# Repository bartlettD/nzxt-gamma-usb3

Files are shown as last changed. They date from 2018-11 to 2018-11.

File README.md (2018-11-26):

# NZXT GAMMA I/O Panel

Replacement front I/O panel for NZXT GAMMA PC case with USB 3.0 ports.

Designed in Autodesk EAGLE v 9.2

PDF Schematics and Board Images are available in the "Docs" directory.

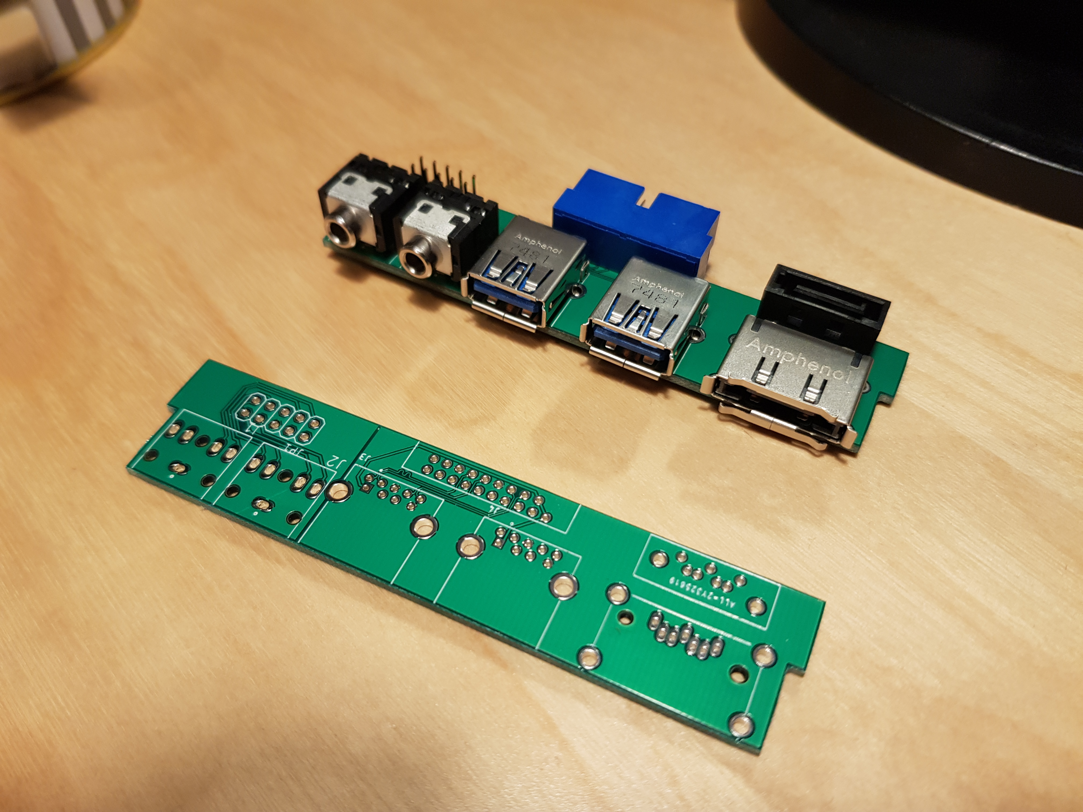
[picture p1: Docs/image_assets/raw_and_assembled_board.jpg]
Raw and Assembled Board


## Features
This is essentially a slight redesign of the original I/O panel for the case.
However the original USB 2.0 ports have been replaced with USB 3.0 ports because
 I like faster transfers and 900mA current limits.

* Intel HD Audio Headphone and Line-in Jacks
* 2x USB 3.0 Ports
* eSATA connector _(Did anyone use this? Maybe replace with SD Card slot one day)_

## Does it work?
**Yes!** 

[Read my tests for USB 3.0 transfers here.](/Docs/transfer-speed-test.md)

[Read about some debug I had to go through to get Audio working properly here.](/Docs/hd-audio-debug.md)

_I didn't test eSATA because nothing uses it. Putting a USB Hub and SD Card
controller IC might be a cool upgrade for the future._

## Licence
The project is licenced under the MIT licence.

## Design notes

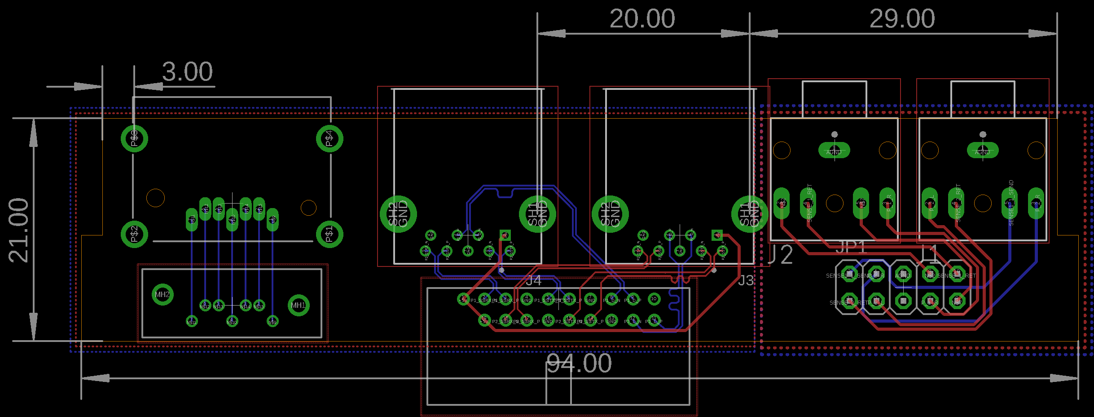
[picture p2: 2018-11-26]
Docs/nzxt-gamma-usb3-layout.png

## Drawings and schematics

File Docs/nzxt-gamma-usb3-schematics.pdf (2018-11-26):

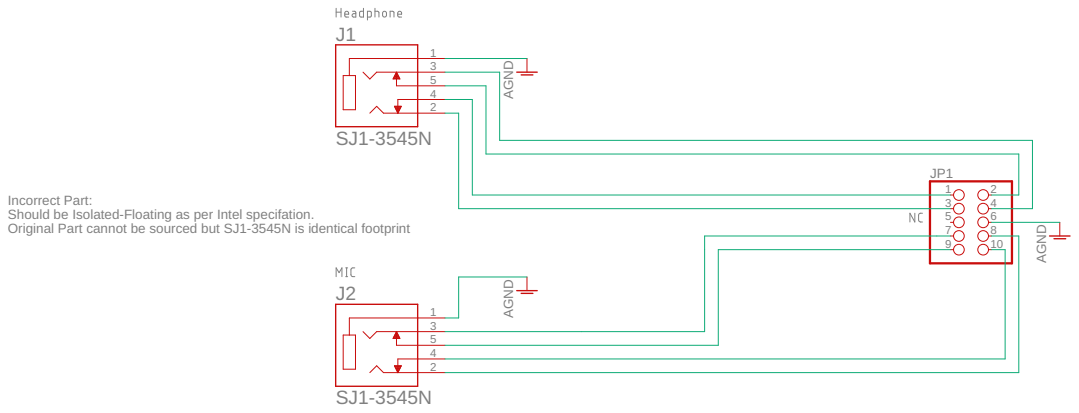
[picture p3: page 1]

Incorrect Part: Should be Isolated-Floating as per Intel specifation. Original Part cannot be sourced but SJ1-3545N is identical footprint

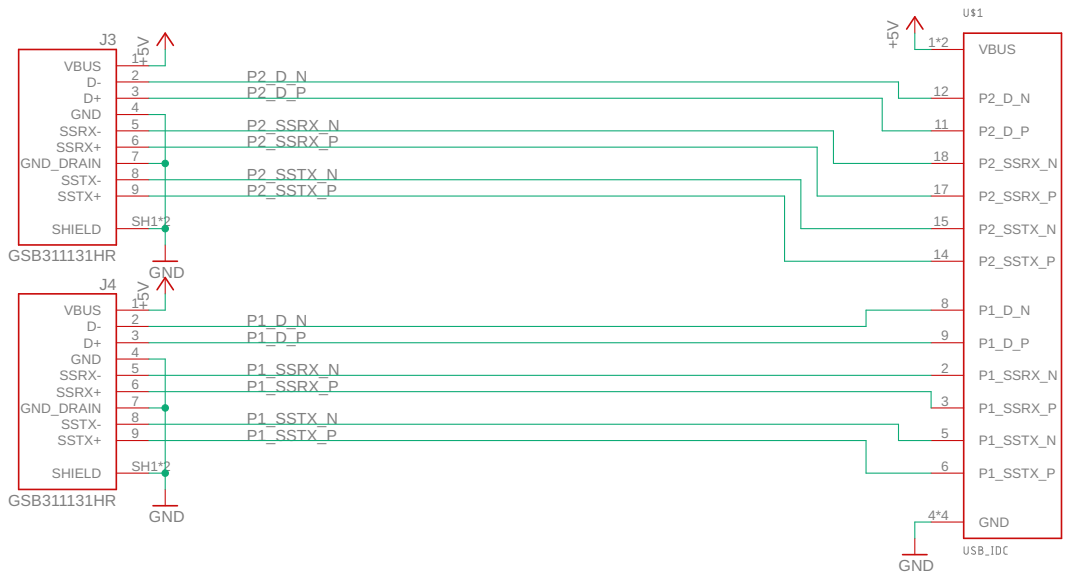
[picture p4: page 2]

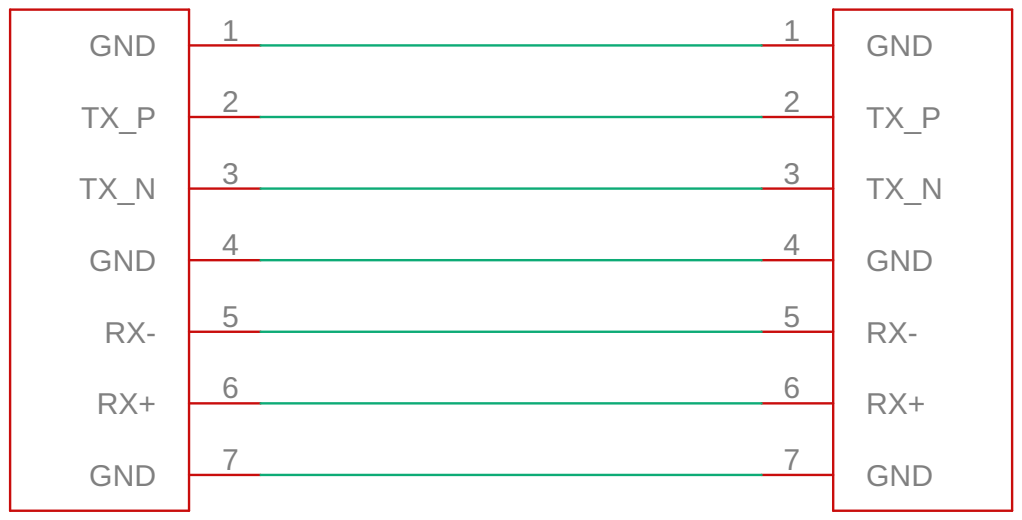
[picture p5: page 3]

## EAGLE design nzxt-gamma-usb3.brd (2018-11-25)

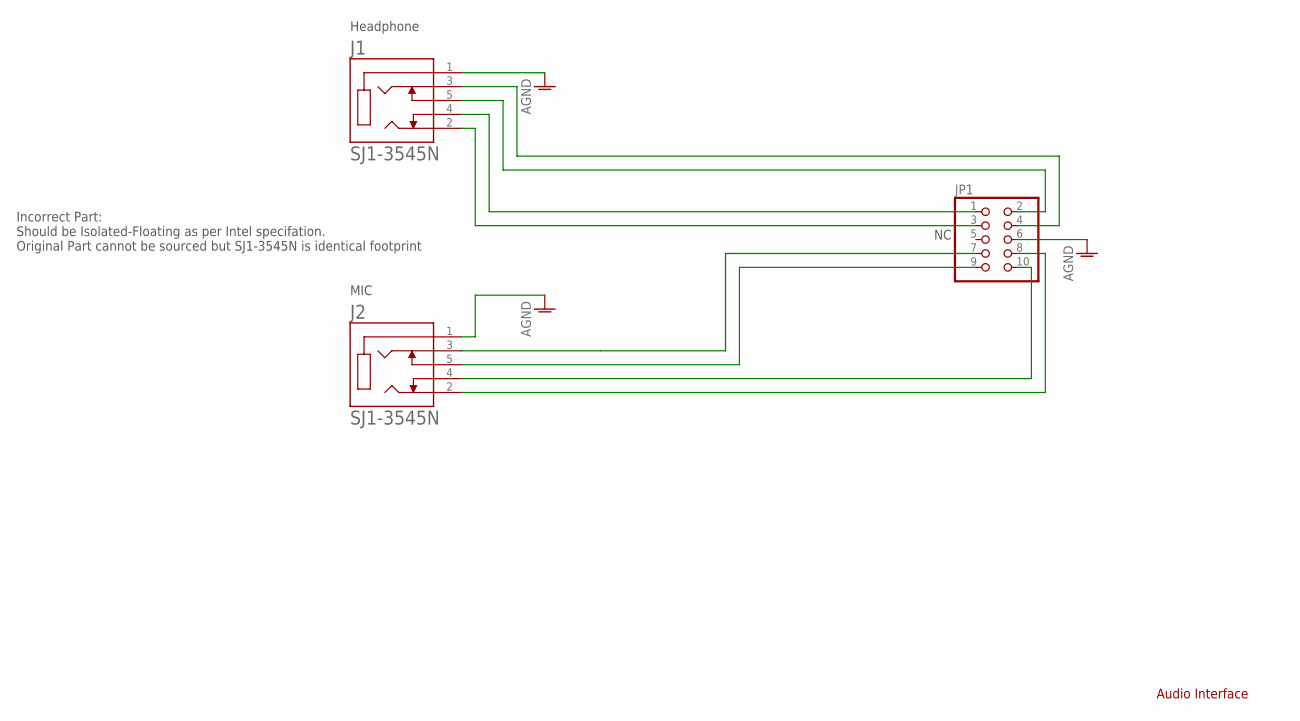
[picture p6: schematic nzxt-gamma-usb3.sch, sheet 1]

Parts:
J1, J2: SJ1-3545N; CUI_SJ1-3545N
JP1: PINHD-2X5; 2X05

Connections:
AGND: J1.1, J2.1, JP1.6
unnamed: J2.2, JP1.8
unnamed: J2.5, JP1.9
P_1_R: J2.3, JP1.7
P_2_L: J1.2, JP1.3
P_2_R: J1.3, JP1.4
SENSE1_1_SEND: J1.5, JP1.2
SENSE_1_RET: J2.4, JP1.10
SENSE_2_RET: J1.4, JP1.1

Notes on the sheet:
Audio Interface
Headphone
MIC
Incorrect Part: Should be Isolated-Floating as per Intel specifation. Original Part cannot be sourced but SJ1-3545N is identical footprint

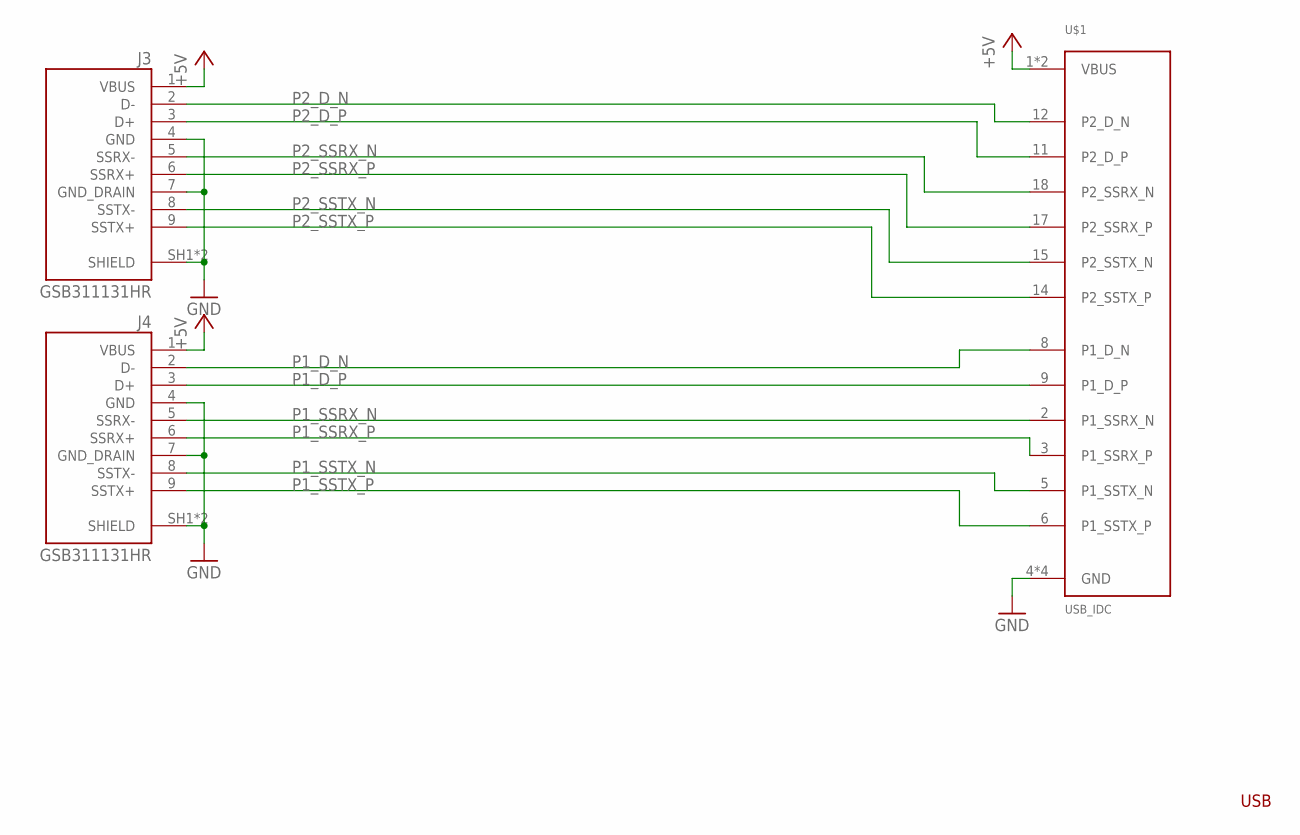
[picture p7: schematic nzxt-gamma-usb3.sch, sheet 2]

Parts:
J3, J4: GSB311131HR; AMPHENOL_GSB311131HR
U$1: USB_IDC; USB3_IDC

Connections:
+5V: J3.1 (VBUS), J4.1 (VBUS), U$1.1 (VBUS), U$1.19 (VBUS)
GND: J3.4 (GND), J3.7 (GND_DRAIN), J3.SH1 (SHIELD), J3.SH2 (SHIELD), J4.4 (GND), J4.7 (GND_DRAIN), J4.SH1 (SHIELD), J4.SH2 (SHIELD), U$1.4 (GND), U$1.7 (GND), U$1.13 (GND), U$1.16 (GND)
P1_D_N: J4.2 (D-), U$1.8 (P1_D_N)
P1_D_P: J4.3 (D+), U$1.9 (P1_D_P)
P1_SSRX_N: J4.5 (SSRX-), U$1.2 (P1_SSRX_N)
P1_SSRX_P: J4.6 (SSRX+), U$1.3 (P1_SSRX_P)
P1_SSTX_N: J4.8 (SSTX-), U$1.5 (P1_SSTX_N)
P1_SSTX_P: J4.9 (SSTX+), U$1.6 (P1_SSTX_P)
P2_D_N: J3.2 (D-), U$1.12 (P2_D_N)
P2_D_P: J3.3 (D+), U$1.11 (P2_D_P)
P2_SSRX_N: J3.5 (SSRX-), U$1.18 (P2_SSRX_N)
P2_SSRX_P: J3.6 (SSRX+), U$1.17 (P2_SSRX_P)
P2_SSTX_N: J3.8 (SSTX-), U$1.15 (P2_SSTX_N)
P2_SSTX_P: J3.9 (SSTX+), U$1.14 (P2_SSTX_P)

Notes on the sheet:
USB

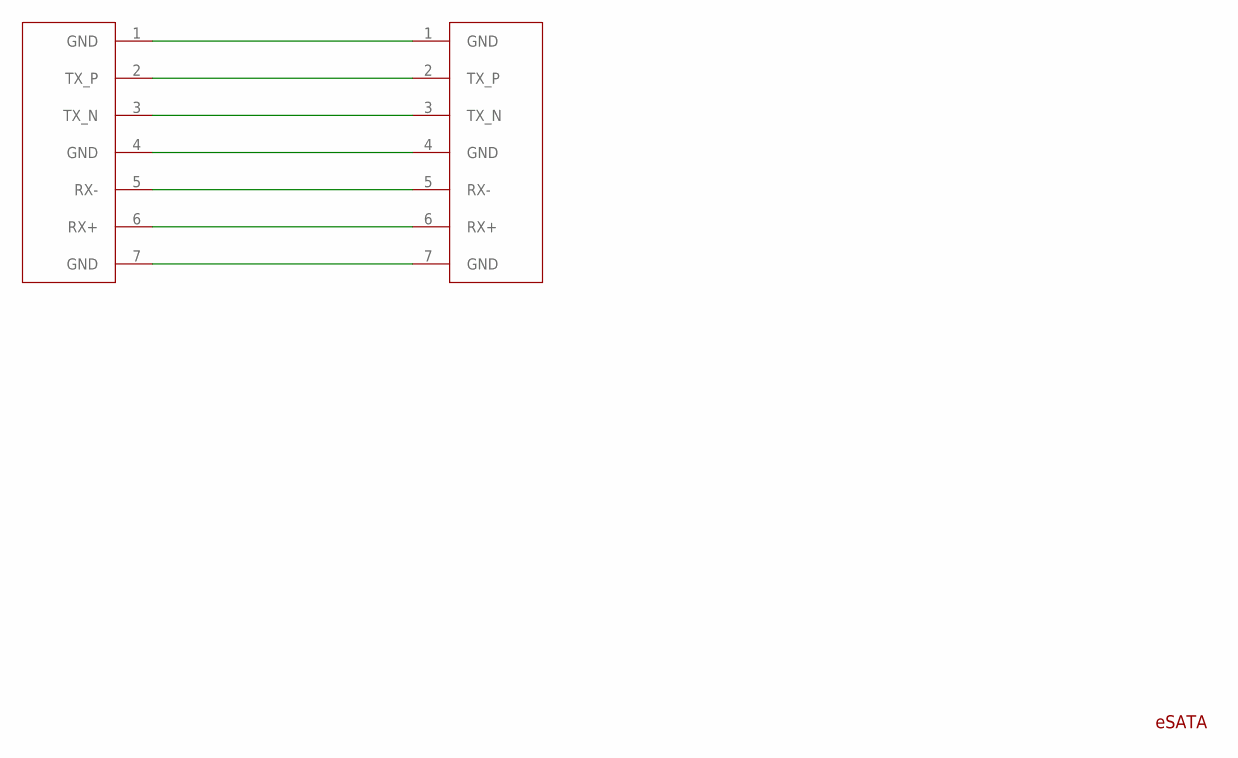
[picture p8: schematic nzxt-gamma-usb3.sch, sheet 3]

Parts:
U$2: G091208300LF
U$3: 0678007001

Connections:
unnamed: U$2.1 (GND), U$3.1 (GND)
unnamed: U$2.4 (GND), U$3.4 (GND)
unnamed: U$2.7 (GND), U$3.7 (GND)
unnamed: U$2.6 (RX+), U$3.6 (RX+)
unnamed: U$2.5 (RX-), U$3.5 (RX-)
unnamed: U$2.3 (TX_N), U$3.3 (TX_N)
unnamed: U$2.2 (TX_P), U$3.2 (TX_P)

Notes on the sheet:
eSATA

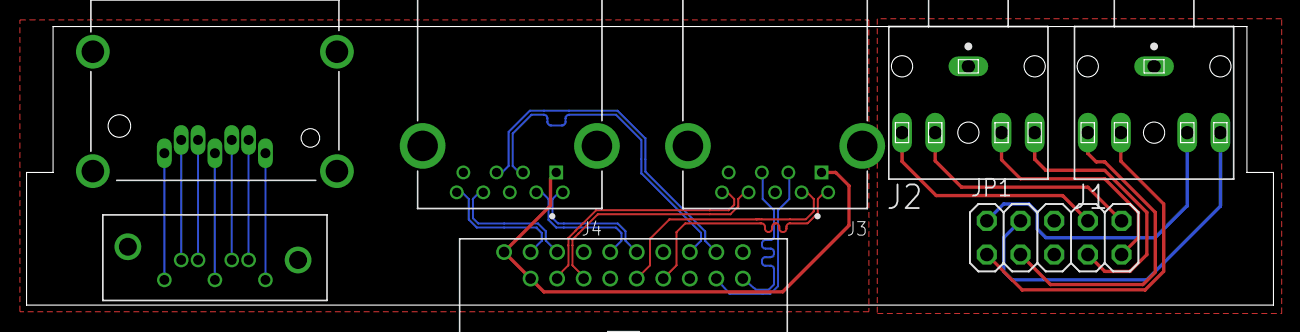
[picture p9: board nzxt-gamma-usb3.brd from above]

Board: 2 copper layers, 94.0 x 21.0 mm, 8 parts (0 on the bottom side), 30 nets.

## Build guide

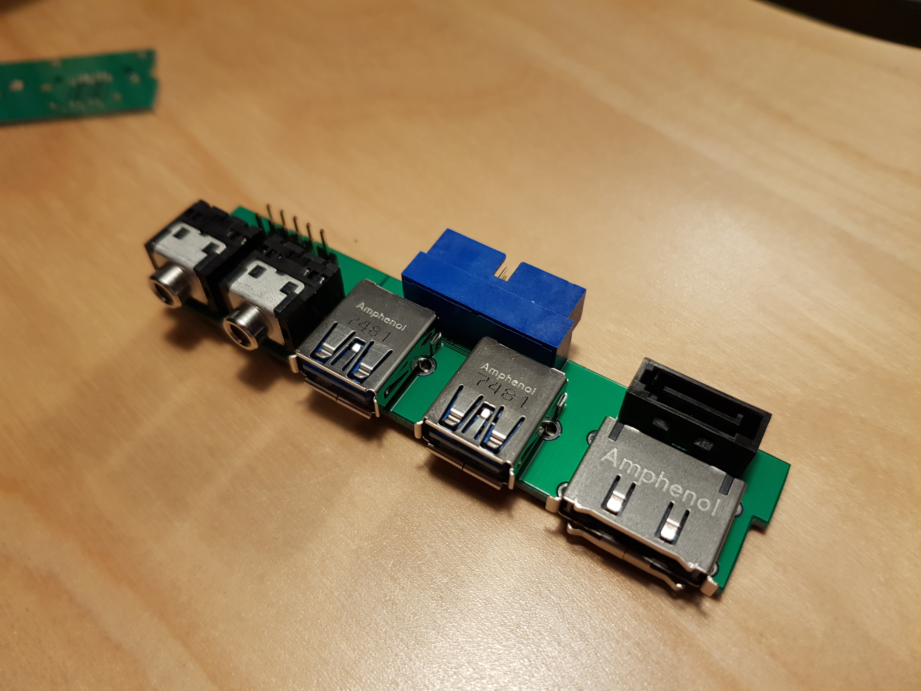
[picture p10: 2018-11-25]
Docs/image_assets/assembled_board.jpg

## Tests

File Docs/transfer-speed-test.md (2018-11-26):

# USB 3.0 Speed Test Results
## Introduction
The main benefit of switching to USB 3.0 in my use case is to achieve higher
transfer rates for USB Drives. There are also additional benefits of a higher
avaible current at the port (900mA vs 500mA) which would be useful for charging
phones and other devices, but was not much of a consideration at the time.

The benchmark shows the the replacement I/O panel works correctly and meets the
same performance level as the on-board ports on the Motherboard.

## Test Method
A common tool for testing speeds of disks is CrystalDiskMark, which is used in 
this test to measure the achieved transfer rate with a USB Drive.

A 100 MiB Sequential/Random Read and Write were performed accross 4 separate USB
ports.

* USB 3.0 Motherboard Ports (For baseline 3.0 comparison)
* The original USB 2.0 front panel ports
* Both Left and Right USB 3.0 front panel ports. (Check for major performance
differences)

## Results
The following chart presents the results of the benchmark.

Speed Test Results for NZXT GAMMA Casemod

It can be seen that in Sequential Read modes, USB 3.0 is much faster than USB 
2.0, which is an expected result. The modified front panel I/O behaves just as
fast as the Motherboard mounted ports.

For Random Reads and Writes we can see little to no performance improvement
between USB 2.0 and 3.0 for any of the 4 ports. This is not completely 
unexpected as the write speeds of Flash memories are much slower to write to
than read.

No major performance differences could be noted between the Left and Right ports.

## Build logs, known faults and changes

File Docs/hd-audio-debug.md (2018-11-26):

# Audio issues
## Introduction
At the outset of the project, it was decided that attempting to salvage parts 
from the original board wouldn't have been worth the effort and risk of damage 
during desoldrring, so equivalent compenents would have to be sourced.

The 3.5mm Audio connectors had to be mechanically identical otherwise they 
wouldn't fit properly against the case plastic.

The CUI SJ1-3545N connectors are mechanically identical to the original 
connectors and were expected to be a zero-effort substitution.

This was not the case.

## Connection issues
During testing of the audio portion of the circuit, the PC reported constant 
disconnection and reconnection of a device when a set of headphones were 
connected to the jack.

After some investigation I came across Intel's [Front-Panel IO Design Guide](Intel_Front_Panel_IO_Connectivity_Design_Guide.pdf)
which describes the theory of operation behind the HD Audio interface standard.

### HD Audio Device Sensing

The Intel HD Audio interface allows front panel jacks to signal user connection 
and disconnection to the Operating System using the SENSE_SEND signal of the 
header.

_Figure 1_ shows Intel's reference implementation of a Front-Panel dongle using 
the HD Audio interface, showing the connections from the dongle header to the 
indiviual audio jacks.

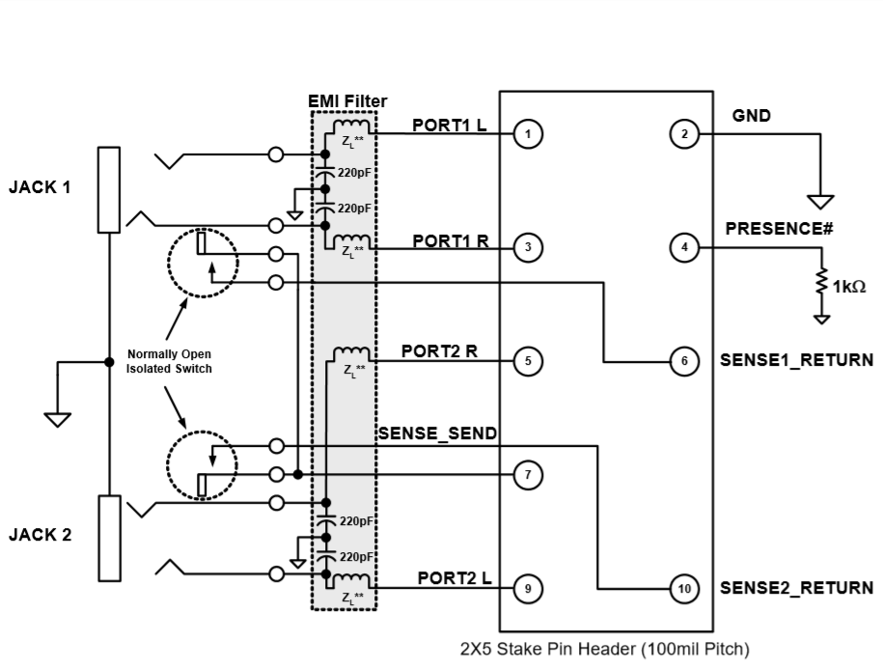
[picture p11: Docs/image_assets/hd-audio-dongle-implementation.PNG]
Intel® HD Audio Front Panel Dongle Implementation

_Figure 1: Intel® HD Audio Front Panel Dongle Implementation_

The previous figure shows that the reference implementation uses "Normally Open 
Isolated Switch" style jacks that connect the SENSE_SEND signal and SENSE_RETURN
signals together so that the CODEC on the motherboard can detect the insertion 
of a plug into the jack.

The connectors selected for this design however are normally closed against the 
Tip and Ring pins of the plug and cause the CODEC to malfunction and cause the 
continual connection and disconnection event generation as described earlier.

## Solution
In this case, a suitable replacement connector which met the specific 
mechanical requirements of the project, as well as the requirement for a 
Normally Open Isolated Switch could not be found.

So I stole the old connectors from the original board.:man_shrugging:

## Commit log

2018-09-10 Added first files
    [nzxt-gamma-usb3.brd, nzxt-gamma-usb3.sch]
2018-09-13 Added USB 3 IDC connector
    [nzxt-gamma-usb3.brd, nzxt-gamma-usb3.sch]
2018-10-25 Repositioned USB and eSATA ports to match casing better. started routing USB traces.
    [nzxt-gamma-usb3.brd, nzxt-gamma-usb3.sch]
2018-10-28 Added sata connector. Length matched USB traces. Changed to managed libraries to generate 3D models.
    [nzxt-gamma-usb3.brd, nzxt-gamma-usb3.sch]
2018-11-07 Updated components on board with better silkscreen
    [nzxt-gamma-usb3.brd, nzxt-gamma-usb3.sch]
2018-11-09 Finished Layout
    [nzxt-gamma-usb3.brd]
2018-11-21 Added Inter Front IO guide. Explains issue with HP jacks failing to register. Need a Normally Open connector rather than SJ1-3545N. Will steal from old board
2018-11-25 Added photos of raw and assembled boards
2018-11-25 Named some nets for debug, added some schematic detail
    [nzxt-gamma-usb3.brd, nzxt-gamma-usb3.sch]
2018-11-26 Fixed some fonts in schematic. Exported schematics as PDF.
    [nzxt-gamma-usb3.sch]
